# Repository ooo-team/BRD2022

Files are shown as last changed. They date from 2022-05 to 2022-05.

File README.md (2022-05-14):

# BRD 2022

BRD_logo

## Решение финала чемпионата по робототехнике от команды ööö

## Строение репозитория

- `robot-code` - код для робота в полуфинале; Написан для Arduino, но легко переписывается для Raspberry Pi.
- `robot-object` - объект для робота в полуфинале
- `robot-schema` - схема подключений для робота на Arduino.
- `service` - сервис на OpenCV для обработки изображения и создания вердикта для робота. Больше подробностей в отчете.
- `report` - отчет о задании.

## Контакты

- [Тетерин Дмитрий](https://t.me/dimoha_zadira)
- [Савицкий Илья](https://t.me/ilya_savitsky)

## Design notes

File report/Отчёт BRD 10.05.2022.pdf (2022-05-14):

# Решение кейса #1 хакатона BRD2022 от команды ööö

## Выполнили Савицкий Илья и Тетерин Дмитрий

# Концепт

Создание робота на базе Arduino Uno. Управление будет осуществляться на основе данных с IP камеры, установленной на корпус робота. В корпус установлены 6 колёс, по 3 с каждой стороны. Каждое на своём моторе постоянного тока. Чтобы контролировать скорость вращения, решено установить драйверы L298N через сервомодуль с I2C PCA9685. Для дополнительной безопасности на переднюю часть дна решено установить 4 ИК датчика.
Проблема в том, что Arduino недостаточно мощная, чтобы обрабатывать поток с камеры (или даже чтобы самостоятельно передавать его на сервер), поэтому хочется отказаться от этого решения в пользу базы Raspberry PI.
Для питания решили использовать два блока по 4 аккумулятора для двигателей (на схеме Блок питания №1) и блок из 4 аккумуляторов типа C для ардуины и GPRS модуля (Блок питания №2).

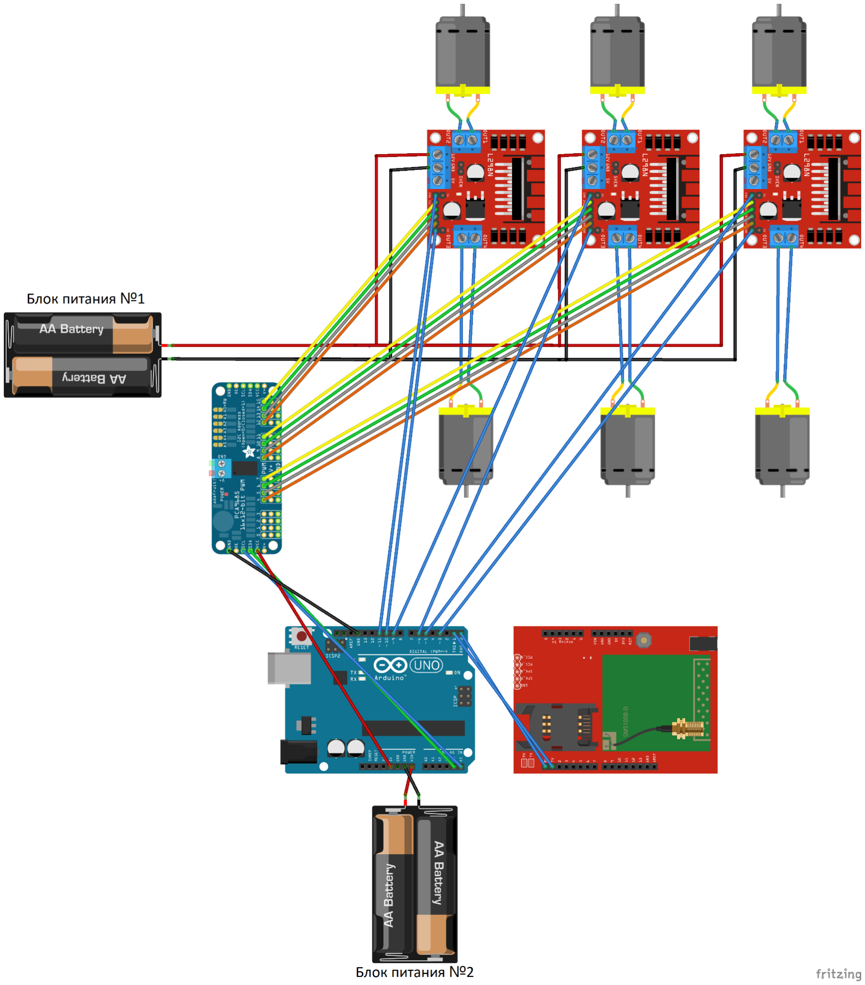
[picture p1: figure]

Полная схема находится тут. (https://github.com/ooo-team/BRD2022/blob/main/robot-schema/robot_bb.png)

## Комплектация “Arduino”

В этой комплектации плата отвечает только за движение робота. Камера, установленная на корпусе, отсылает поток на сервер, на котором исполняется код, анализирующий поток с помощью OpenCV. Эта библиотека определяет препятствия, стоящие на пути, и выдаёт вердикт: ехать вперёд, остановиться или совершать разворот в ту или иную сторону.
Ардуино периодически обращается к этому серверу. Для этого нужен любой подходящий чипсет(в нашем случае - SIM800 в составе GPRS Shield, однако код умеет обращаться с более широким спектром чипсетов). Однако два устройства, обращающиеся через интернет, в одном устройстве, – достаточно грустная затея.

## Комплектация “Raspberry PI”

Этот микропроцессор достаточно мощный, чтобы самостоятельно справляться с обработкой изображения. Соответственно, отпадает необходимость в GPRS модуле, а также дополнительный риск с тем, что интернет-соединение может быть нестабильно. Более того, вместо IP-камеры можно использовать обычную вебкамеру.

# Описание серверной части (в случае с Raspberry это часть внутренней логики робота)

Для обработки запросов с робота был разработан сервис, анализирующий трассу перед роботом. При получении картинки с IP камеры первым делом строятся контуры при помощи алгоритма Кэнни. (https://en.wikipedia.org/wiki/Canny_edge_detector) Далее, получив информацию о контурах, они аппроксимируются полиномами для того, чтобы впоследствии по ним было легко построить так называемые “ограничивающие коробки” - специальные объекты, которые помогают определить примерное положение объекта и процент экрана, который он занимает. После этого все “коробки” классифицируются по принадлежности к левой или правой половине экрана и по занимаемой ими площади, из чего система делает вывод о том, поворачивать роботу влево или вправо. Все это реализовано без методов машинного обучения и на быстрых библиотеках OpenCV и numpy, а значит сервис достаточно быстрый, чтобы обрабатываться в реальном времени (в том числе, и на Raspberry Pi).

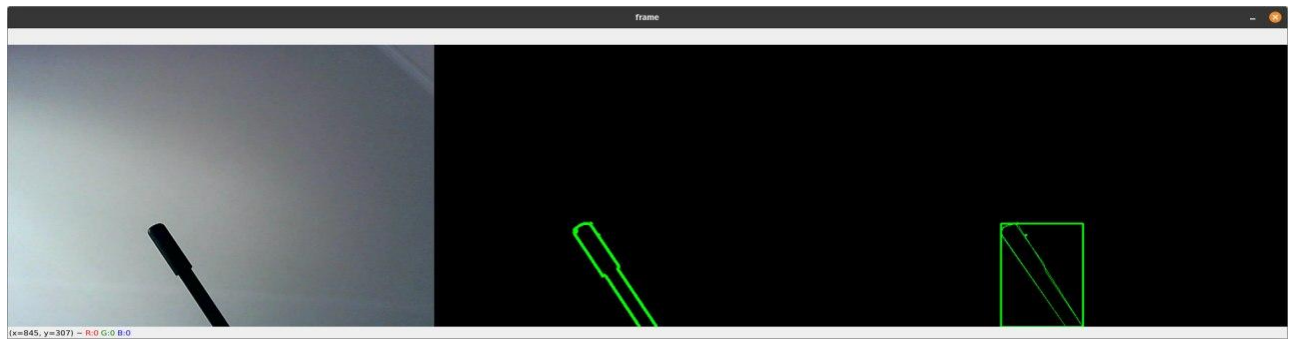
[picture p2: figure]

# Особенности 3D Модели

Габариты робота максимальные возможные – 25см x 25см. Высота зависит от тестового груза.

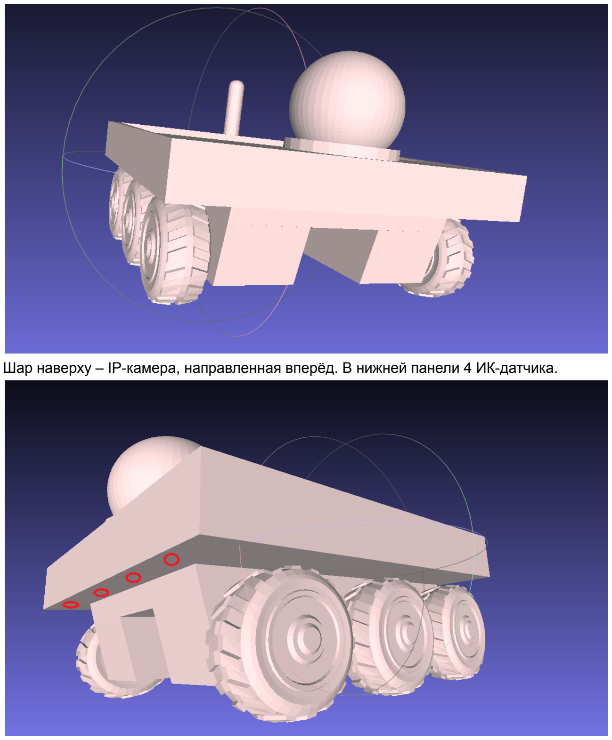
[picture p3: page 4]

Шар наверху – IP-камера, направленная вперёд. В нижней панели 4 ИК-датчика.

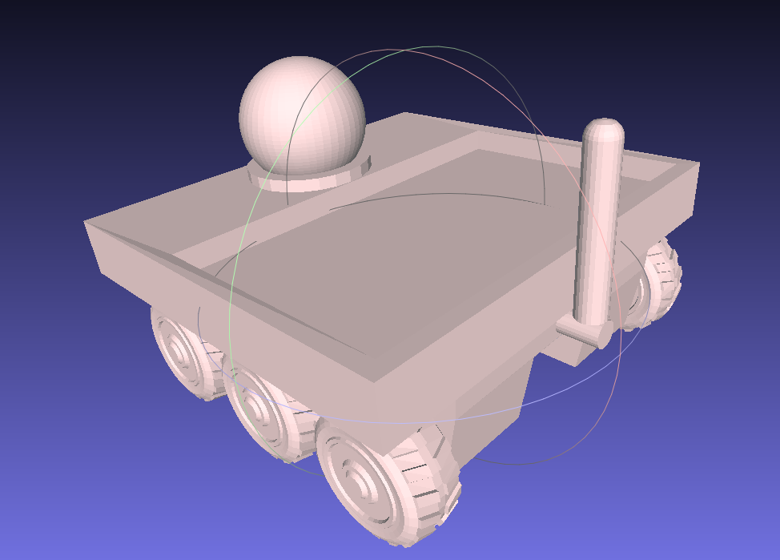
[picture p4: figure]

Сзади - антенна GPRS модуля. Углубление – багажник. Под углублением место для электроники и блоков питания.
В силу особенностей трассы, которую предстоит пройти, решено сделать 6 колёс и путём расположения блоков питания в отсеке рядом с колёсами стянуть центр тяжести вниз, чтобы не иметь проблем с начальным крутым спуском и последующим подъёмом. В планах добавить амортизацию колёсам и, возможно, “спарить” ведущие пары колёс наподобие колёс в конструкции “Лунохода-1”.
Чтобы обойти цилиндрическое препятствие во второй половине трассы, сделали продольный клиренс. Соответственно, в этом месте OpenCV будет настроен таким образом, чтобы, когда робот проезжает это препятствие, он оставлял его строго по центру.

# Почему наше решение лучшее

- Высокая проходимость за счёт шести колёс со своими двигателями
- Использование современных технологий в области компьютерного зрения
- Бесконечная расширяемость возможностей путём улучшения кодовой базы обработки изображения (без изменения кодовой базы самих роботов)
- Высокая надёжность за счёт страхующих ИК-датчиков
- Лёгкая и простая масштабируемость за счёт серверной архитектуры

# Что готово

- Проанализирована трасса. В соответствии с препятствиями на ней были выявлены характеристики, которыми должен обладать робот
- Проанализирован рынок комплектующих
- Разработан прототип 3D-модели робота
- Разработан код сервиса компьютерного зрения
- Разработан код “ходовой” части робота на Arduino Uno
- Создана схема контактов робота. Зафиксированы большинство комплектующих

# План развития

- По чему есть наработки:
- ‘полировка” и “отладка” модели робота. Концепция зафиксирована до первых испытаний. Имеется ввиду само качество модели
- отладки и доработка сервиса компьютерного зрения
- По чему нет наработок:
- отладка кода “ходовой части” на Arduino
- доработка сервиса компьютерного зрения - добавление функций трекинга препятствий во время движения робота

# Строение репозитория

Все, что было выполнено нами на протяжении этого хакатона(за исключением этого документа) выложено здесь. (https://github.com/ooo-team/BRD2022) Вот как этот репозиторий устроен:
- robot-code
- robot.ino - код “ходовой” части робота для Arduino. Зависит от библиотек Adafruit_PWMServoDriver и TinyGsmClient. Пареметрами этого кода являются адрес и порт сервера, на котром работает сервис компьютерного зрения, а так же некоторые другие параметры, связанные с работой SIM-карты.
- robot-object
- robot.obj - объектный файл робота. Без текстурных координат.
- robot-schema
- robot.fzz - схема соединений в роботе в формате Fritzing.
- robot_bb.png - экспортируемая картинка соединений. Может отставать на пару коммитов от схемы во Fritzing
- service
- Pipfile & Pipfile.lock - файлы системы контроля зависимостей pipenv
- viewer.py - скрипт, позволяющий интерактивно просмотреть работу всех алгоритмов компьютерного зрения в реальном времени
- verdict.py - скрипт оценки окружения при помощи компьютерного зрения с убранной визуализацией с целью ускорения.

# Развертка системы

## 1. Склонировать репозиторий

git clone https://github.com/ooo-team/BRD2022

## 2. Зависимости кода ходовой части

Для компиляции кода ходовой части из менеджера библиотек Arduino установите следующие библиотеки с исходным кодом
- TinyGSM (https://github.com/vshymanskyy/TinyGSM)
- Adafruit PWM Driver (https://github.com/intoyuniot/Adafruit_PWMServoDriver)
После этого возможно верифицировать, скомпилировать и загрузить код на Arduino Uno

## 3. Синхронизация зависимостей для сервиса компьютерного зрения

Контроль зависимостей осуществляется при помощи Pipenv. Убедитесь что он установлен у Вас перед использованием

cd service
pipenv shell
pipenv sync
После чего можно запускать сервис

# Комплектующие

- Напечатанный на 3D принтере корпус (первый прототип модели приложен)
- ИК датчики (4x, ссылка, (https://iarduino.ru/shop/Sensory-Datchiki/infrakrasnyy-datchik-obnaruzheniya-prepyatstviy.html) 190*4=760₽)
- Драйвер L298N (3x, ссылка, (https://market.yandex.ru/offer/EISlid00ptaNEmg0S84_tQ?hid=7076558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) 3*450 = 1350₽)
- Cервомодуль PCA9685 (ссылка, (https://aliexpress.ru/item/4000468996665.html?sku_id=10000001887185582) 250₽)
- Колесо с двигателем и редуктором (6x,ссылка, (https://amperkot.ru/products/koleso_s_dc_dvigatelem/23934275.html) 6*110=660₽); Возможно, понадобится этот комплект двигатель+редуктор: ссылка (https://amperkot.ru/products/motor_s_reduktorom_lobraznyiy_uglovoy_148/24327381.html)

## Комплектация “Arduino”

- IP камера (например, такая, (https://aliexpress.ru/item/4000097603791.html?item_id=4000097603791&sku_id=12000024020663879) 4900₽)
- Arduino UNO (ссылка, (https://amperka.ru/product/arduino-uno) 3540₽)
- GPRS плата (ссылка, (https://amperka.ru/product/arduino-gprs-shield) 3340₽)
- Сим-карта с выходом в интернет для Arduino и Камеры

## Комплектация “Raspberry PI”

- Raspberry PI (хочется верить, что около 4000₽, но в силу некоторых нюансов получается (https://www.dns-shop.ru/product/cab4135738283332/mikrokomputer-raspberry-pi-4-model-b/) 15000₽)
- Камера (ссылка, (https://aliexpress.ru/item/1005003629759085.html?sku_id=12000026567415855) 1000₽)

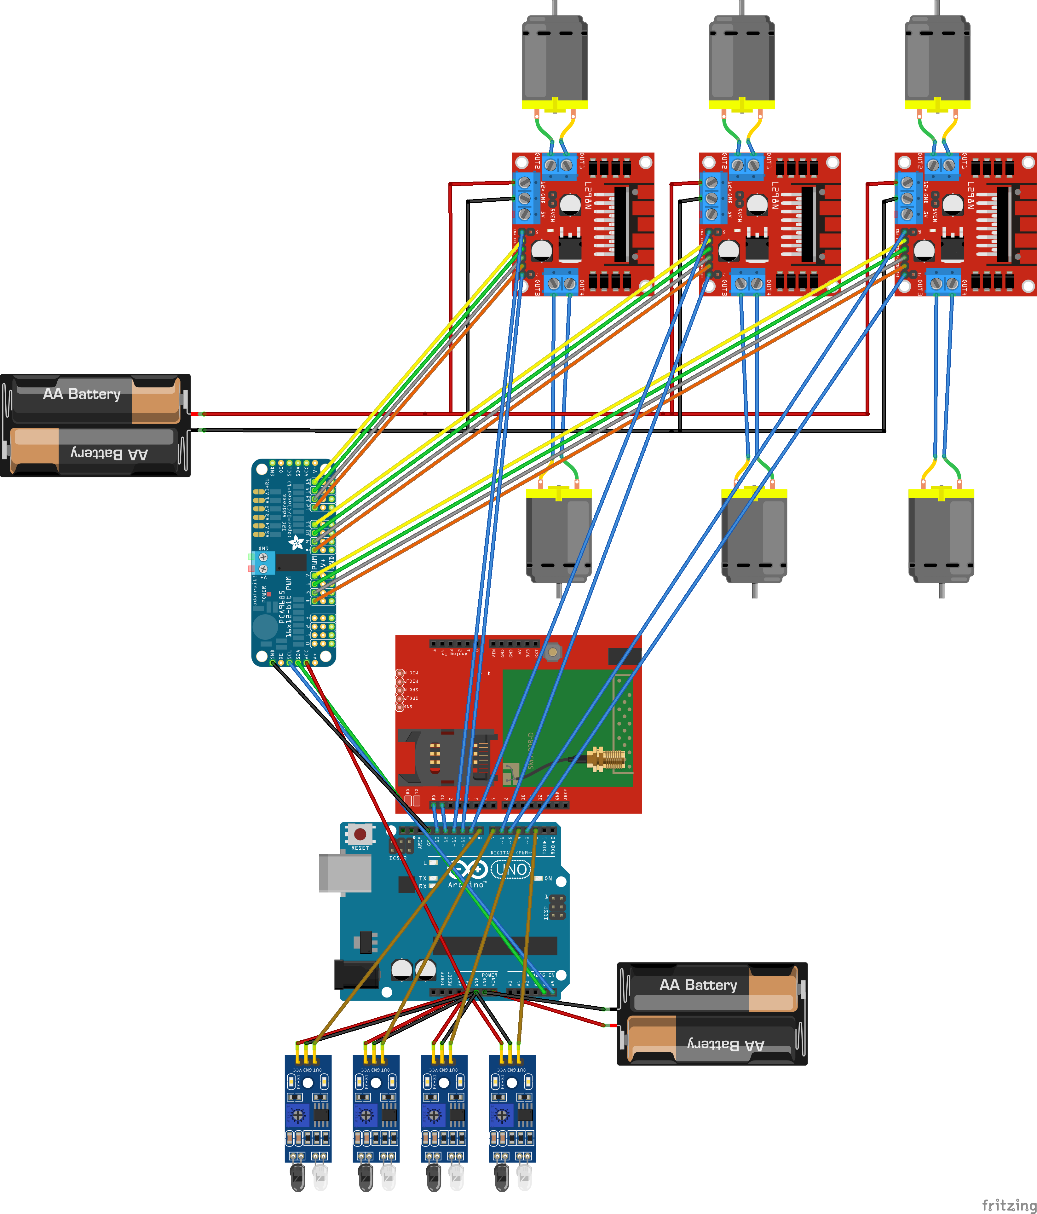
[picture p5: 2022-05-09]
robot-schema/robot_bb.png

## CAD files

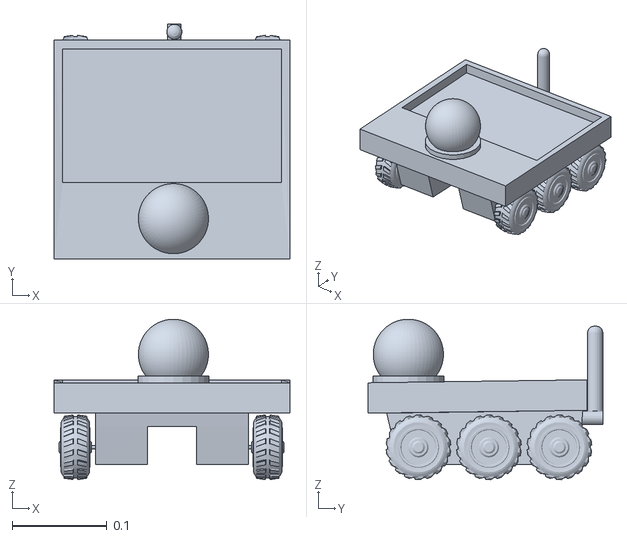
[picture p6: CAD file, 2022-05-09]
robot-object/robot.obj
0.249 x 0.247 x 0.169

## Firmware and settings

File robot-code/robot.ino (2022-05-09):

#define TINY_GSM_MODEM_SIM800
#include <SoftwareSerial.h>
SoftwareSerial SerialAT(12, 13);
#if !defined(TINY_GSM_RX_BUFFER)
#define TINY_GSM_RX_BUFFER 650
#endif
#define GSM_AUTOBAUD_MIN 9600
#define GSM_AUTOBAUD_MAX 115200
#define GSM_PIN ""
#include <Adafruit_PWMServoDriver.h>
#include <ArduinoHttpClient.h>
#include <TinyGsmClient.h>
#include <Wire.h>

Adafruit_PWMServoDriver pwm = Adafruit_PWMServoDriver();
TinyGsm modem(SerialAT);
TinyGsmClient client(modem);

const char apn[] = "my apn";
const char gprsUser[] = "";
const char gprsPass[] = "";

const char server[] = "server";
const uint16_t port = 123;
HttpClient http(client, server, port);

enum class FirstDriver {
  Left_go = 4,
  Left_back = 5,
  Right_go = 6,
  Right_back = 7,
  Left_PWM = 5,
  Right_PWM = 3
};

enum class SecondDriver {
  Left_go = 8,
  Left_back = 9,
  Right_go = 10,
  Right_back = 11,
  Left_PWM = 9,
  Right_PWM = 6
};

enum class ThirdDriver {
  Left_go = 12,
  Left_back = 13,
  Right_go = 14,
  Right_back = 15,
  Left_PWM = 11,
  Right_PWM = 10
};

enum class IRArray {
  Left_sensor = 2,
  Left_center_sensor = 4,
  Rigth_center_sensor = 7,
  Right_sensor = 8
};

#define DC_FORWARD(driver, speed)                                              \
  pwm.setPWM(int(driver::Left_go), 4096, 0);                                   \
  pwm.setPWM(int(driver::Right_go), 4096, 0);                                  \
  pwm.setPWM(int(driver::Left_back), 0, 4096);                                 \
  pwm.setPWM(int(driver::Right_back), 0, 4096);                                \
  digitalWrite(int(driver::Right_PWM), speed);                                 \
  digitalWrite(int(driver::Left_PWM), speed);

#define DC_BACK(driver, speed)                                                 \
  pwm.setPWM(int(driver::Left_go), 0, 4096);                                   \
  pwm.setPWM(int(driver::Right_go), 0, 4096);                                  \
  pwm.setPWM(int(driver::Left_back), 4096, 0);                                 \
  pwm.setPWM(int(driver::Right_back), 4096, 0);                                \
  digitalWrite(int(driver::Right_PWM), speed);                                 \
  digitalWrite(int(driver::Left_PWM), speed);

#define DC_STOP(driver)                                                        \
  pwm.setPWM(int(driver::Left_go), 0, 4096);                                   \
  pwm.setPWM(int(driver::Right_go), 0, 4096);                                  \
  pwm.setPWM(int(driver::Left_back), 0, 4096);                                 \
  pwm.setPWM(int(driver::Right_back), 0, 4096);                                \
  digitalWrite(int(driver::Right_PWM), 0);                                     \
  digitalWrite(int(driver::Left_PWM), 0);

#define DC_LEFT(driver, speed)                                                 \
  pwm.setPWM(int(driver::Left_go), 0, 4096);                                   \
  pwm.setPWM(int(driver::Right_go), 4096, 0);                                  \
  pwm.setPWM(int(driver::Left_back), 4096, 0);                                 \
  pwm.setPWM(int(driver::Right_back), 0, 4096);                                \
  digitalWrite(int(driver::Right_PWM), speed);                                 \
  digitalWrite(int(driver::Left_PWM), speed);

#define DC_RIGHT(driver, speed)                                                \
  pwm.setPWM(int(driver::Left_go), 4096, 0);                                   \
  pwm.setPWM(int(driver::Right_go), 0, 4096);                                  \
  pwm.setPWM(int(driver::Left_back), 0, 4096);                                 \
  pwm.setPWM(int(driver::Right_back), 4096, 0);                                \
  digitalWrite(int(driver::Right_PWM), speed);                                 \
  digitalWrite(int(driver::Left_PWM), speed);

void setup() {
  Serial.begin(9600);

  TinyGsmAutoBaud(SerialAT, GSM_AUTOBAUD_MIN, GSM_AUTOBAUD_MAX);

  modem.restart();
  if (GSM_PIN && modem.getSimStatus() != SIM_ANTITHEFT_LOCKED) {
    modem.simUnlock(GSM_PIN);
  }

  // pwm shield but not really pwm
  pwm.begin();
  pwm.setPWMFreq(1000);

  pinMode(int(FirstDriver::Left_PWM), OUTPUT);
  pinMode(int(FirstDriver::Right_PWM), OUTPUT);

  pinMode(int(SecondDriver::Left_PWM), OUTPUT);
  pinMode(int(SecondDriver::Right_PWM), OUTPUT);

  pinMode(int(ThirdDriver::Left_PWM), OUTPUT);
  pinMode(int(ThirdDriver::Right_PWM), OUTPUT);

  pinMode(int(IRArray::Left_sensor), INPUT);
  pinMode(int(IRArray::Left_center_sensor), INPUT);
  pinMode(int(IRArray::Right_sensor), INPUT);
  pinMode(int(IRArray::Rigth_center_sensor), INPUT);

  Wire.setClock(400000);
}

void run(uint8_t speed) {
  DC_FORWARD(FirstDriver, speed)
  DC_FORWARD(SecondDriver, speed)
  DC_FORWARD(ThirdDriver, speed)
}

void back(uint8_t speed) {
  DC_BACK(FirstDriver, speed)
  DC_BACK(SecondDriver, speed)
  DC_BACK(ThirdDriver, speed)
}

void brake() {
  DC_STOP(FirstDriver)
  DC_STOP(SecondDriver)
  DC_STOP(ThirdDriver)
}

void left(uint8_t speed) {
  DC_LEFT(FirstDriver, speed)
  DC_LEFT(SecondDriver, speed)
  DC_LEFT(ThirdDriver, speed)
}

void right(uint8_t speed) {
  DC_RIGHT(FirstDriver, speed)
  DC_RIGHT(SecondDriver, speed)
  DC_RIGHT(ThirdDriver, speed)
}

void loop() {
  // if all four are bad - go back
  if (digitalRead(int(IRArray::Left_sensor)) &
      digitalRead(int(IRArray::Left_center_sensor)) &
      digitalRead(int(IRArray::Right_sensor)) &
      digitalRead(int(IRArray::Rigth_center_sensor)) == HIGH) {
    back(255);
    delay(3000);
    brake();
  }
  // GPRS connection parameters are usually set after network registration
  Serial.print(F("Connecting to "));
  Serial.print(apn);
  if (!modem.gprsConnect(apn, gprsUser, gprsPass)) {
    Serial.println(" fail");
    delay(10000);
    return;
  }
  Serial.println(" success");

  if (modem.isGprsConnected()) {
    Serial.println("GPRS connected");
  }
  Serial.print(F("Performing HTTP GET request... "));
  int err = http.get("/get_next");
  if (err != 0) {
    Serial.println(F("failed to connect"));
    delay(10000);
    return;
  }

  int status = http.responseStatusCode();
  Serial.print(F("Response status code: "));
  Serial.println(status);
  if (!status) {
    delay(10000);
    return;
  }

  String body = http.responseBody();
  Serial.println(F("Response:"));
  switch (body.toInt()) {
  case 0:
    run(255);
    break;
  case 1:
    left(255);
    break;
  case 2:
    right(255);
    break;
  case 3:
    back(255);
    break;
  case 4:
    brake();
    break;
  }
}

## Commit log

2022-05-04 added scematics
    [robot.fzz]
2022-05-08 added an evaluator prototype
2022-05-09 added robot object
    [robot.obj]
2022-05-09 robot code + schema rework
    [robot.fzz]
2022-05-09 added pwm submodule
2022-05-09 edited routing
    [robot.fzz]
2022-05-09 new schematics
    [robot.fzz]
2022-05-09 new bot schema; bot code
    [robot.fzz]
